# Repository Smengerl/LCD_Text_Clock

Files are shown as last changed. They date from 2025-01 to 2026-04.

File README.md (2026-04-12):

# LCD Text Clock





A text-based clock using an LCD display with I2C interface on an ESP microcontroller with automatic NTP time sync.

## Table of Contents
- [Mechanics](#mechanics)
- [Electronics](#electronics)
- [Software](#software)
- [Usage](#usage)
- [Customization Ideas](#customization-ideas)
- [Acknowledgements](#acknowledgements)
- [Development](#development)
- [License](#license)
- [Authors](#authors)

- Displays the current time and date as text like "five minutes to four"
- 16x2, 40*2 or 20x4 character LCD display support
- Customizable animations
- Supports buttons to flip between modes showing different informationwhich can be easily extended 
- Automatic backlight switching and dimming (optional feature) 
- Automatic time synchronization using NTP

The whole project rather serves as an example how text on a LCD display can be beautifully presented to users and can easily be extended/adapter to match your usecase.

| Without pushbuttons | With 4 pushbuttons |
| --- | ---|
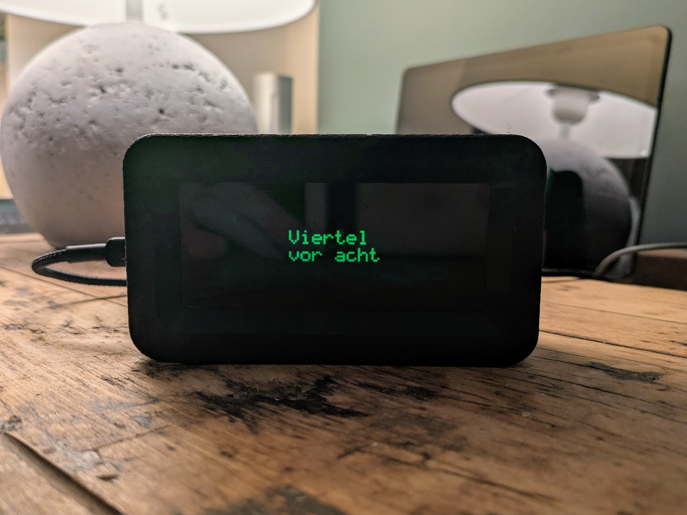
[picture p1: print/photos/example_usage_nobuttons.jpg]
example_usage_nobuttons
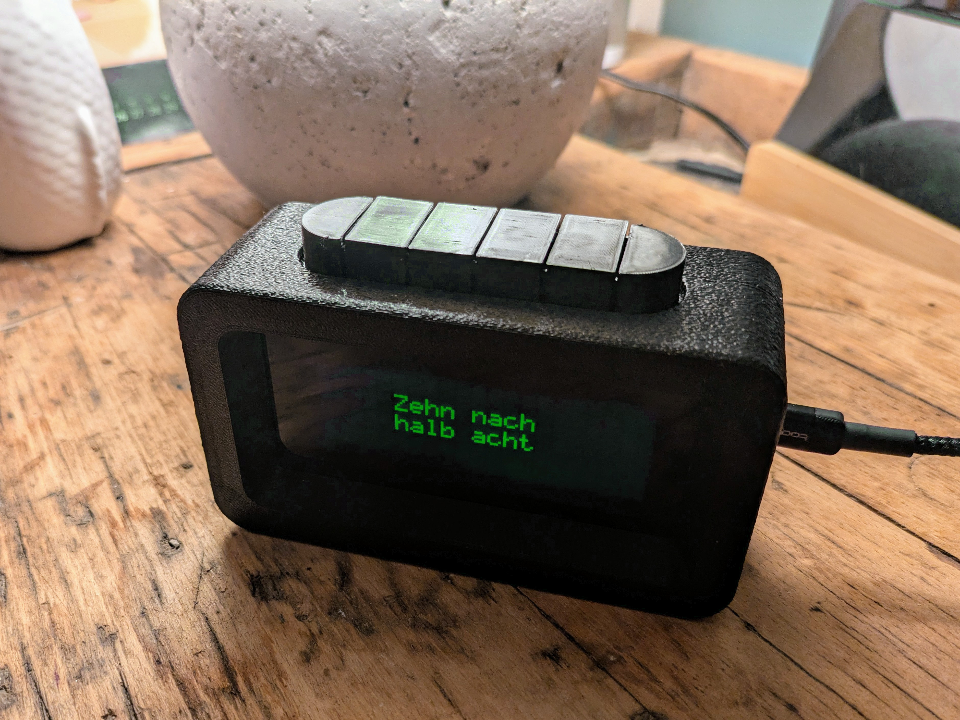
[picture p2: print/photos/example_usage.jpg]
example_usage
|   |  |

# Index
- [Mechanics](#Mechanics)
- [Electronics](#Electronics)
- [Software](#Software)
- [Usage](#Usage)
- [Customization ideas](#customization_ideas)
- [Acknowledgements](#Acknowledgements)

## Mechanics

Two different types of housings for 20*4 LCD displays are provided.
Using the acrylic plate on top of the LCD is optional but gives a cleaner look (not used in the example photos)

Very simple housing that consist of a front and a back piece (Shown is the version with the pushbuttons)

| Front | Back | Isometric |
| --- | --- | --- |
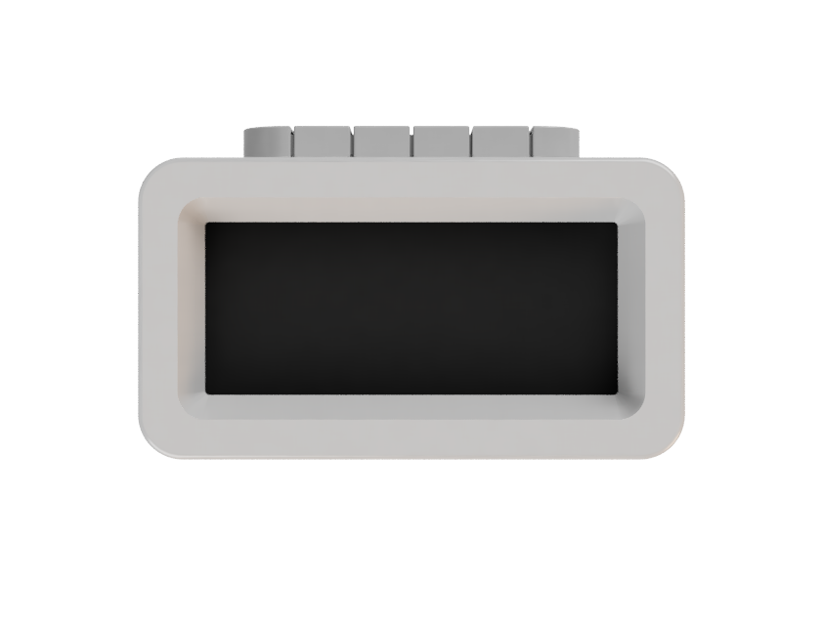
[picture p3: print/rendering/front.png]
front
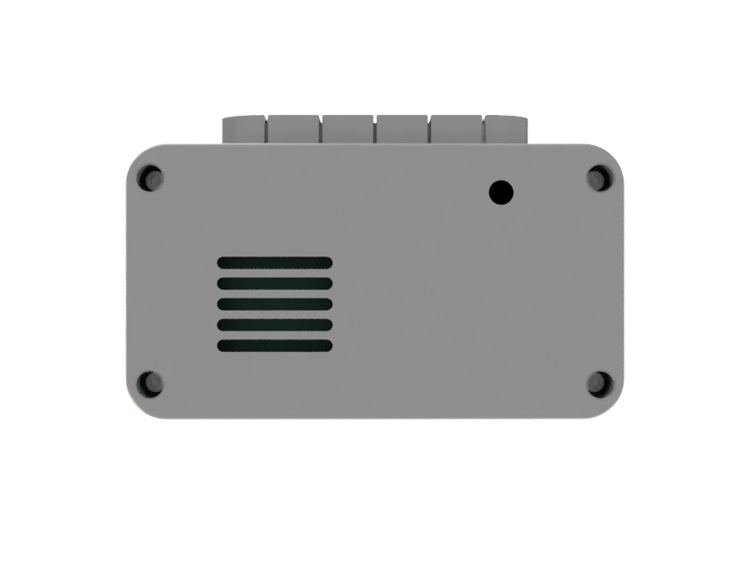
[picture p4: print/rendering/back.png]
back
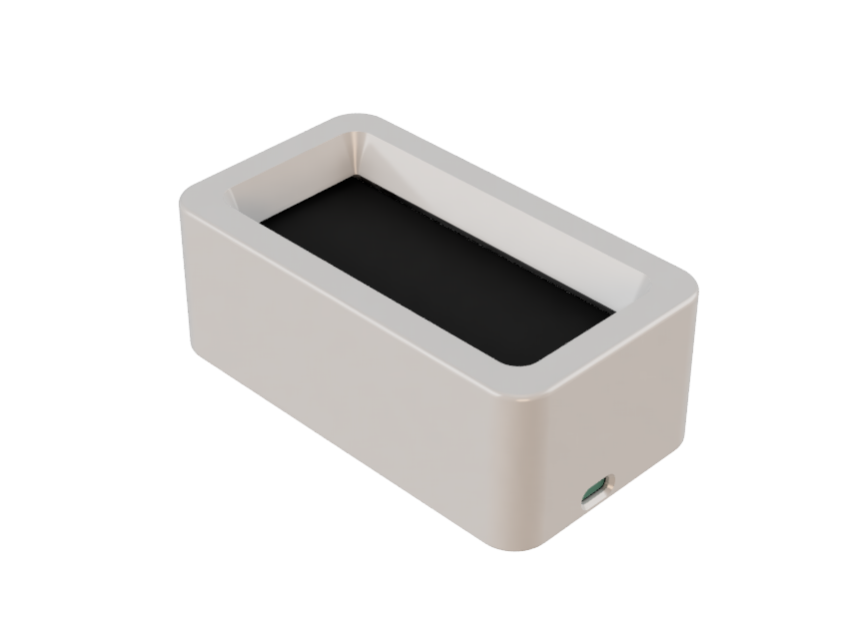
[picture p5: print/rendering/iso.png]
|  |  |  |
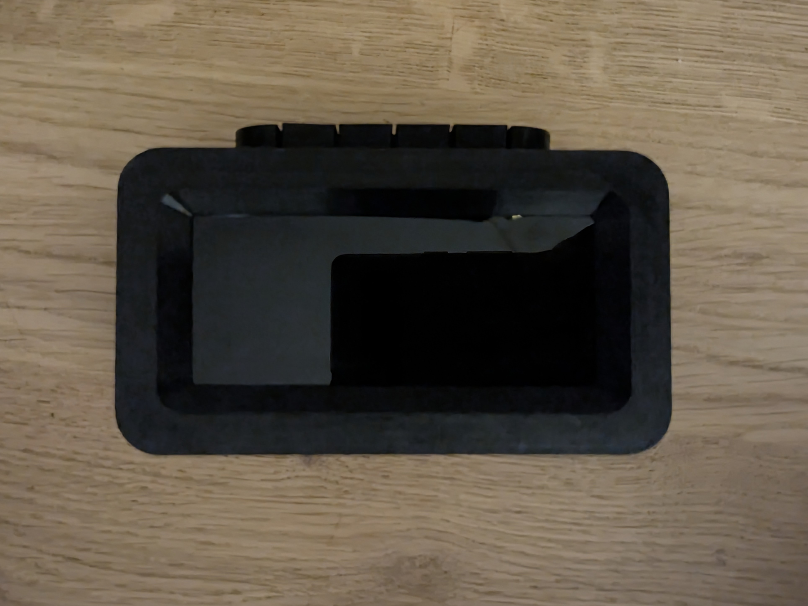
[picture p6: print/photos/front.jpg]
front
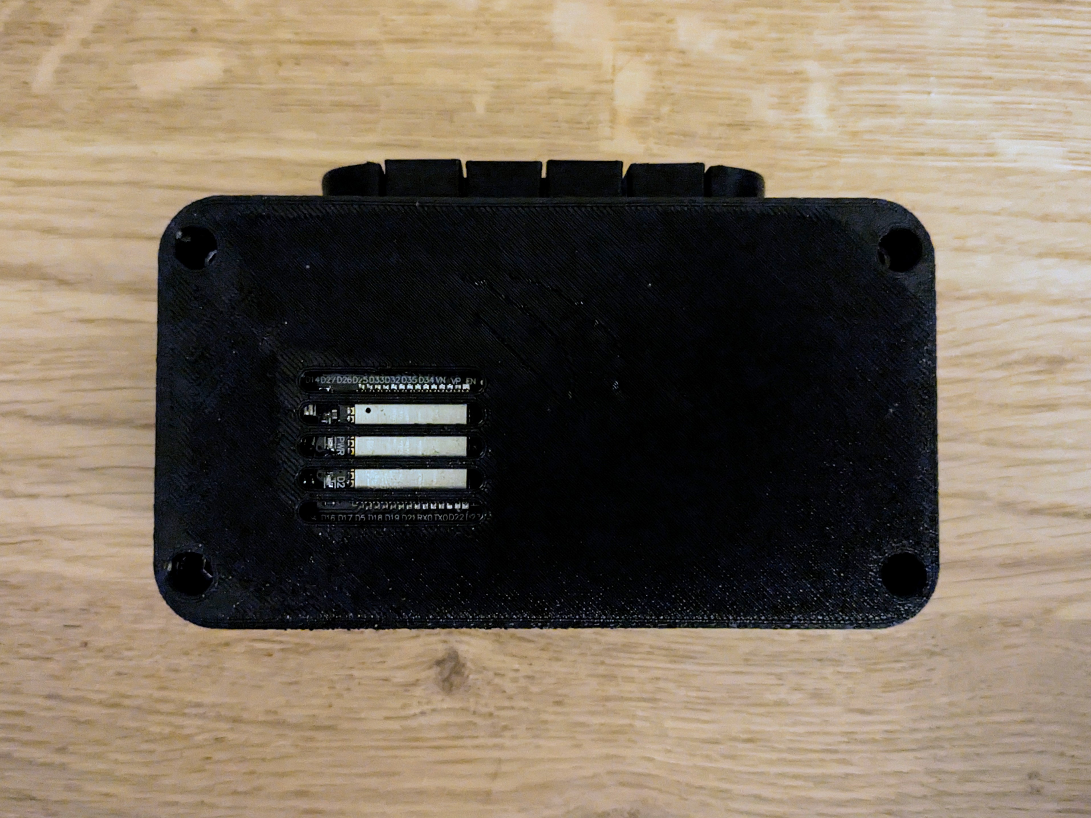
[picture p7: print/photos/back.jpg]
back
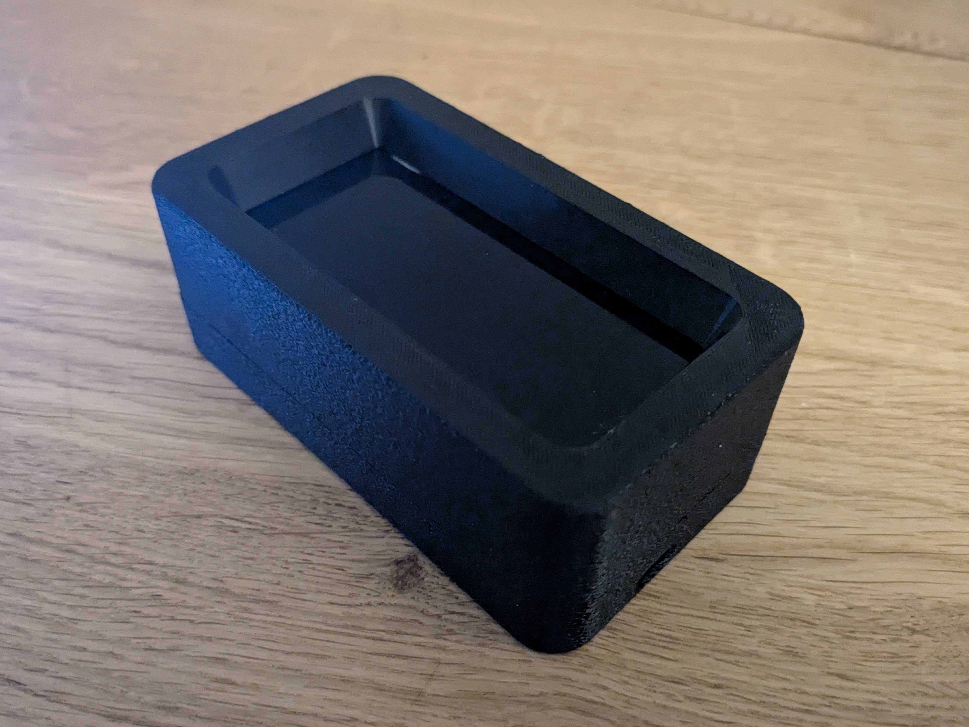
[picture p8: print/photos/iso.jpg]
|  |  |  |

### 3D-Printed Parts

1. Without pushbuttons:

| Filename | Thumbnail | Required | Notes |
| --- | ---| --- | ---|
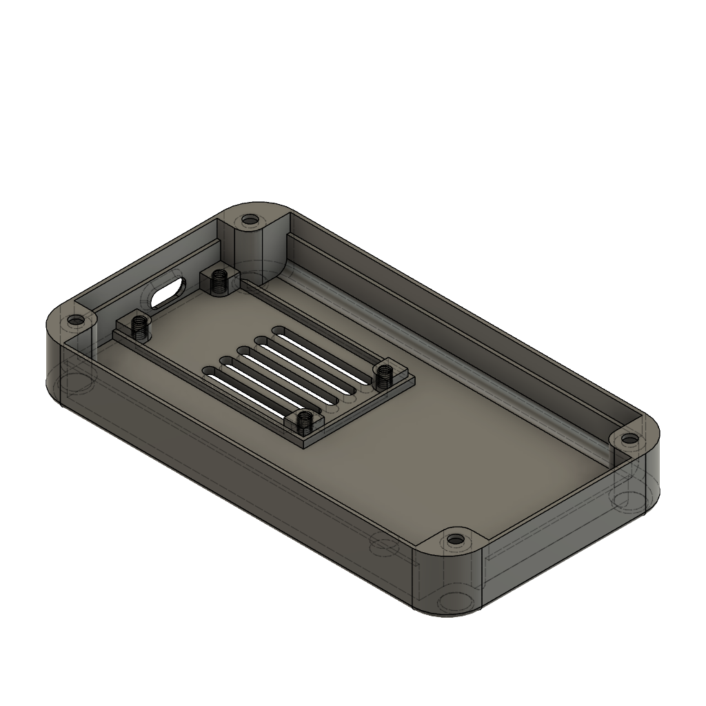
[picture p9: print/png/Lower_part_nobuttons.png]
Lower part
| `./print/stl/Lower_part_nobuttons.stl` |  | 1 | |
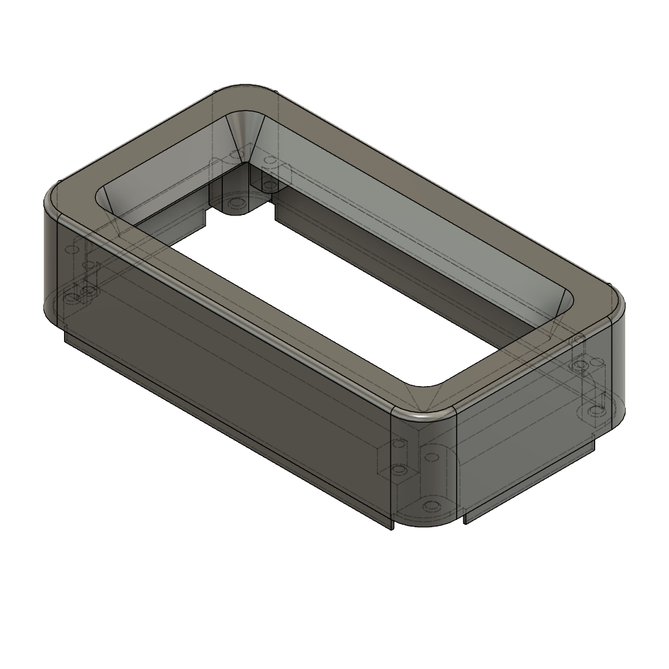
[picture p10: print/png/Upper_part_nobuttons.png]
Upper part
| `./print/stl/Upper_part_nobuttons.stl` |  | 1 | |

2. With 4 pushbuttons:

| Filename | Thumbnail | Required | Notes |
| --- | ---| --- | ---|
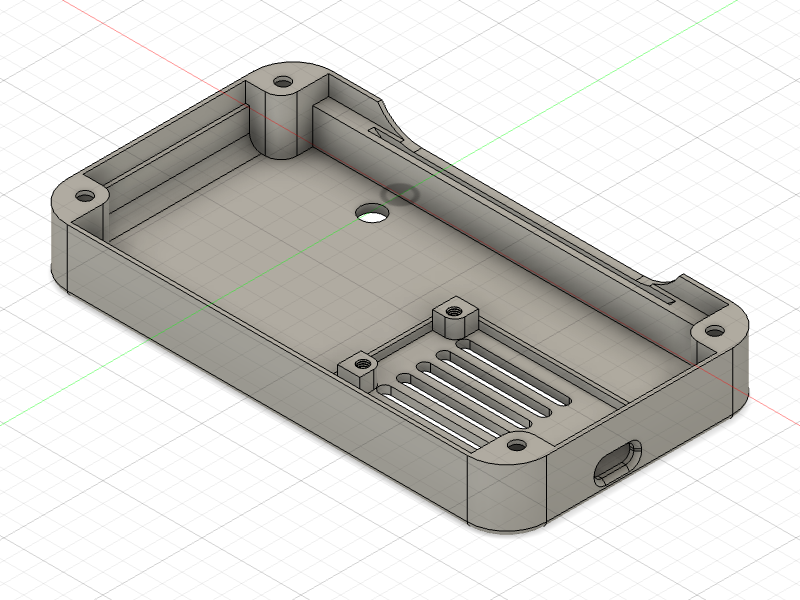
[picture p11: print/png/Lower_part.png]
Lower part
| `./print/stl/Lower_part.stl` |  | 1 | |
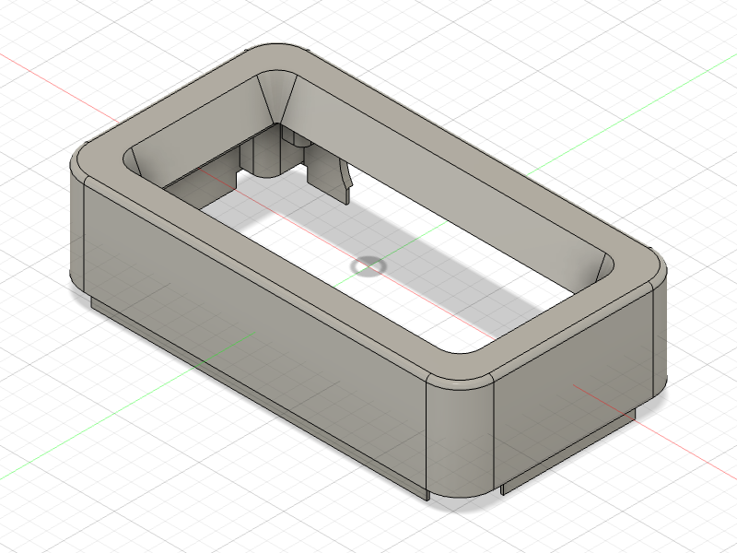
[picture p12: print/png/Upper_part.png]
Upper part
| `./print/stl/Upper_part.stl` |  | 1 | |
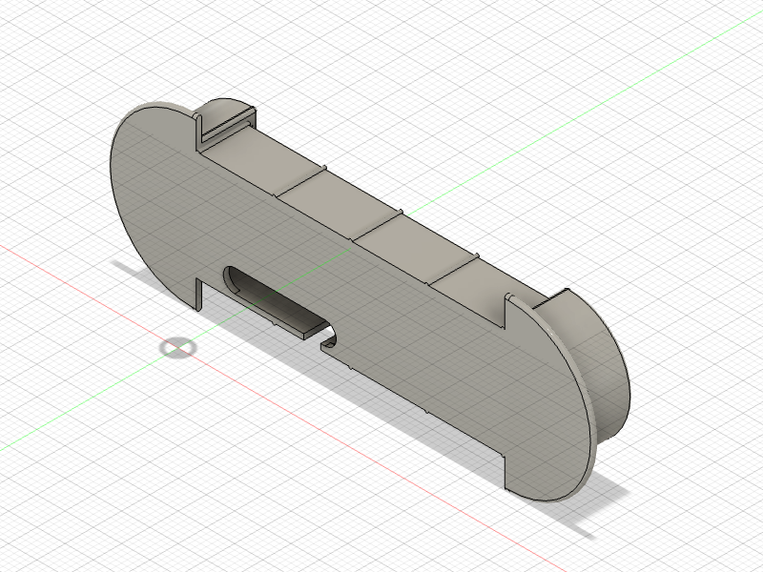
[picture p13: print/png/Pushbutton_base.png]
Pushbutton_base
| `./print/stl/Pushbutton_base.stl`  |  | 1 | |
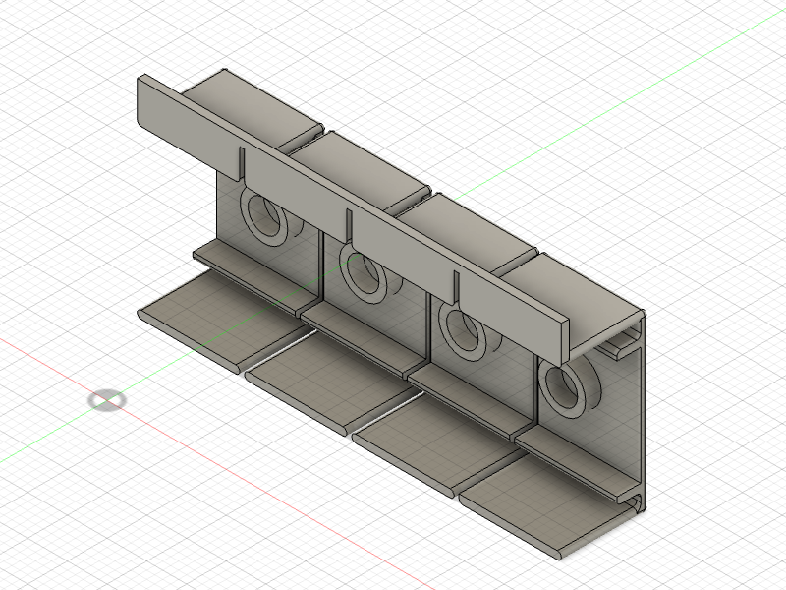
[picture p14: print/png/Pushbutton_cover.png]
Pushbutton_cover
| `./print/stl/Pushbutton_cover.stl` |  | 1 | |

Printer settings:
- All printed parts designed for PETG. 
- Best experience on my printer was to print the front upside down (the actual front of the case facing the print bed) as this does not require any supports. For a cleaner look you can consider to print it reversed with ironing enabled but note that this requires a lot of support material. 
- Using fuzzy skin for all outside walls creates a nice look
- Use ironing to get a nice clean look on top of the pushbutton baseplate and cover
- No rafts/brim etc. reguired for any model.

### Required parts

| Name | Spec | Required | Notes |
| --- | --- | --- | ---|
| countersunk screw | M3 5mm, e.g. DIN EN ISO 4762  | 4 | To attach ESP to back of housing |
| countersunk screw | M3 5mm, e.g. DIN EN ISO 4762  | 4 | To attach display to back of housing |
| cylinder head screw | M3 10mm | 4 | To fix back and front of housing |
| semi-transparent acrylic board | max 2mm, 95-100mm * 40-50mm | 1 | Optional, for cleaner look |

### Assembly

- The ESP is screwed to the back of the housing.
- The acrylic plate is glued to the front (optional)
- The LCD is then fixed via screws to the front
- When using the pushbuttons, click the pushbutton PCB into the baseplate and snap-in the pushbutton top cover. Then slide it into the lower part of the housing  
- Finally the lower and the upper part of the housing are assembled and tightened via the screws.
- Consider using some hot glue to make sure everything stays in place

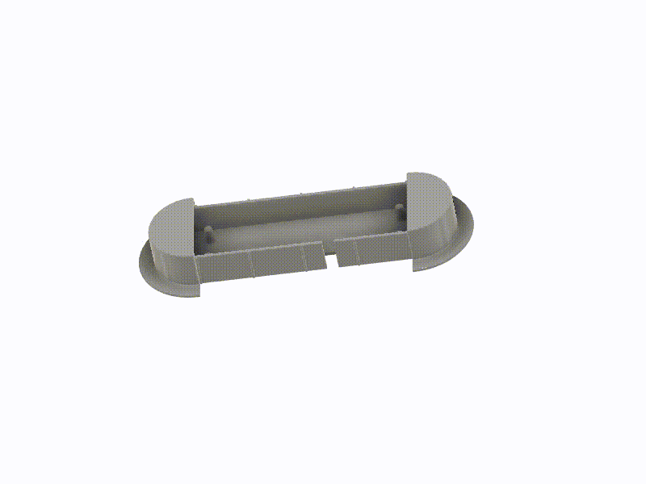
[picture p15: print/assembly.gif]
assembly


## Electronics

### Part list

| Unit price | Quantity | Partname | Example | Notes |
| --- | --- | --- | --- | ----- |
| 5 USD | 1 | ESP32 Dev module | <a href="https://de.aliexpress.com/item/1005006474308440.html">AliExpress</a> | USB-C Version |
| 5 USD | 1 | 2004 HD44780 character LCD module | <a href="https://de.aliexpress.com/item/1005006656450425.html">AliExpress</a> | Consider "negative" LCD (colored fonts on black background), as this gives a clean look, esp. when placing under an acrylic plate |
| 1-2 USD | 1 | PCF8574 I2C module for LCD | <a href="https://de.aliexpress.com/item/1005006686091415.html">AliExpress</a> | You might want to pick one that has a jumper to enable/disable backlight as we can "misuse" this to dim the backlight via GPIO |
| 1-2 USD | Optional | 4 button module | <a href="https://de.aliexpress.com/item/1005007272677522.html">AliExpress</a> | Optional | Unsolder SMD LED |

Total cost about 10-15 USD!

### Schematics

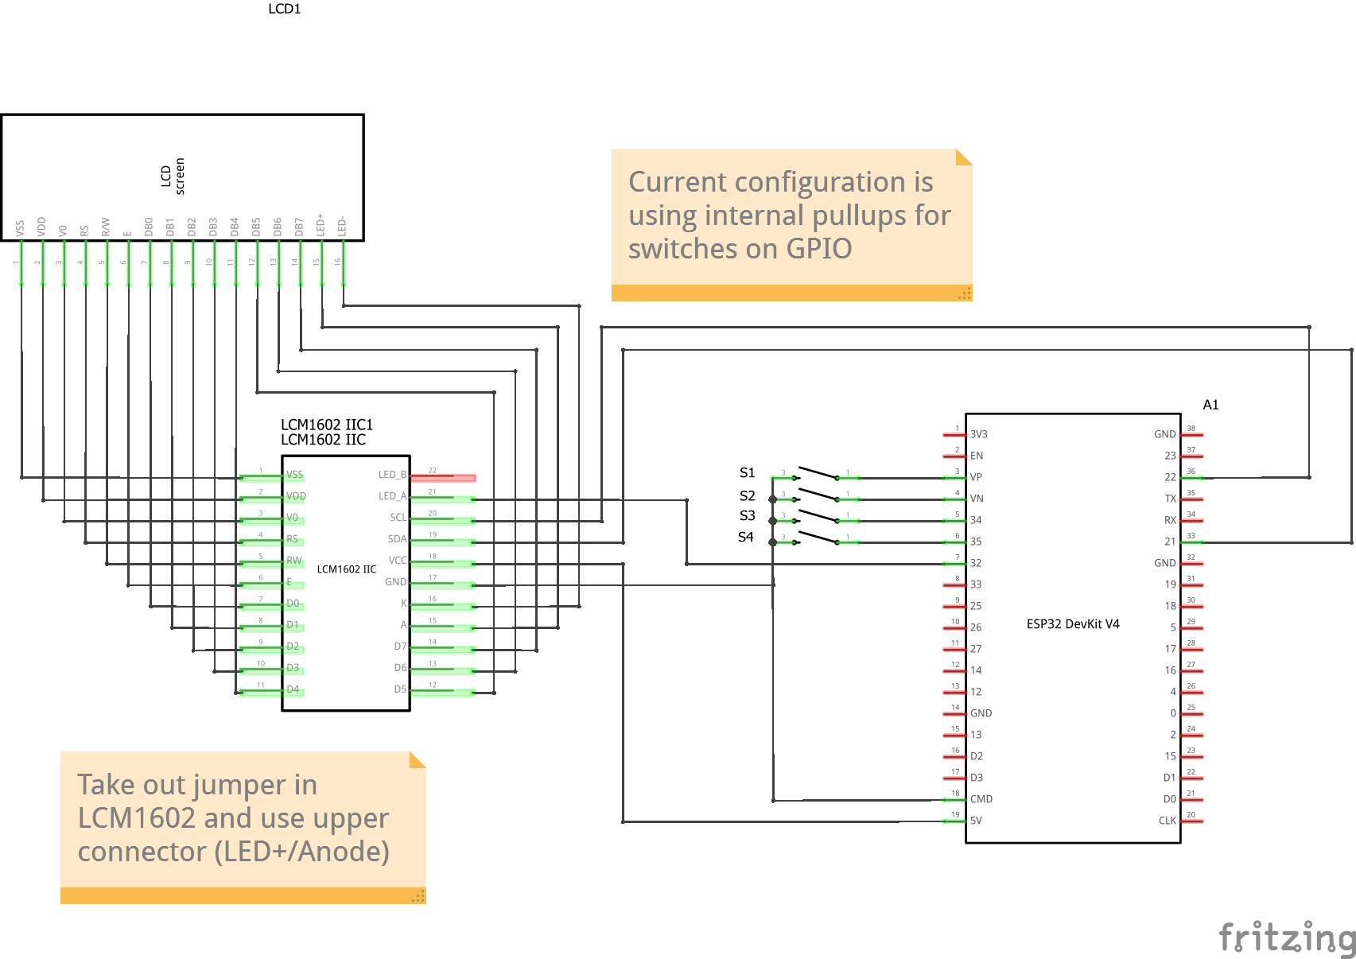
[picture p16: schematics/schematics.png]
schematics


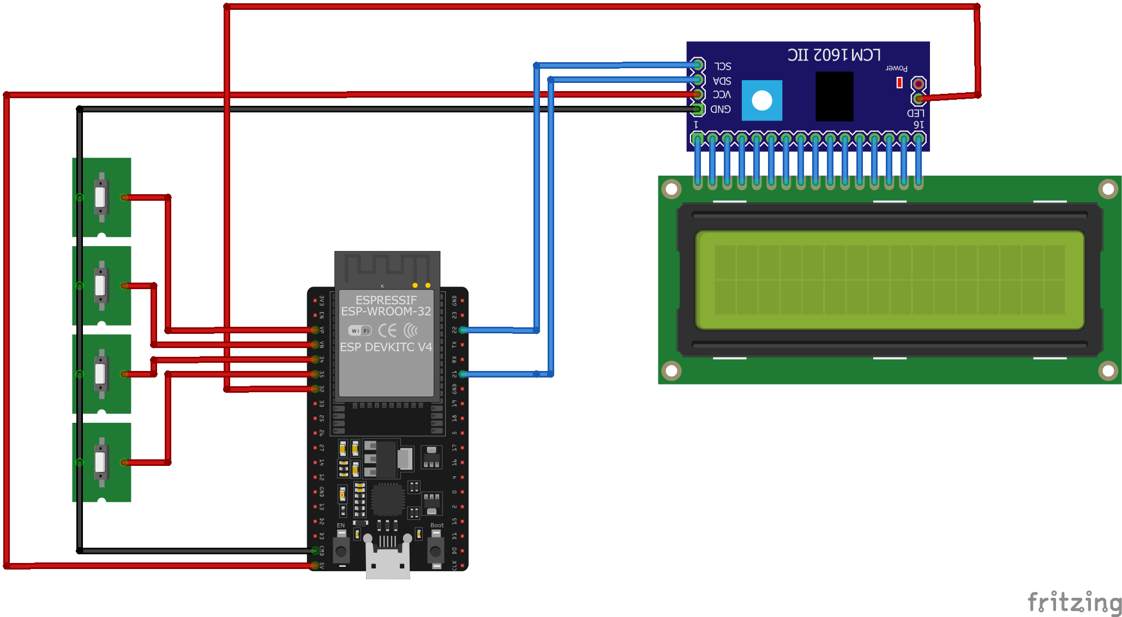
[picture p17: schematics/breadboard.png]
schematics


## Software

### Prerequisites

- PlatformIO
- LiquidCrystal_I2C (via PIO)
- ESPDateTime (via PIO)
- WiFiManager (via PIO)

### Installation

1. Clone the repository:
   ```sh
   git clone https://github.com/smengerl/LCD_Text_Clock.git
2. Open the project in PlatformIO.
3. Wait for PIO to configure and download the required libraries
4. Compile and upload the project to your ESP32 microcontroller.

## Usage
- Power on the ESP32.
- On first usage only: Configure the ESP to your local WiFi. For this, connect to the ESP's access point and use the default configuration page to enter your WLAN SSID and password 
- Wait for NTP sync
- The current time will be displayed on the LCD display.
- Use the (optional) buttons to flip through the pages and watch the animation

## Customization ideas

- Modify the text and backlight settings in the code to customize the display.
- Adjust the NTP server and time zone settings as needed.
- Add more pages, e.g. showing sensor data
- Get weather forecast via internet and display it on the screen with custom characters
- Write your own animations for text transitions

## Acknowledgements
- ESPDateTime library by mcxiaoke
- WiFiManager by wnatth3
- LiquidCrystal_I2C by marcoschwartz

## Development

Contributions are welcome.  
See `CONTRIBUTING.md` for details and follow the `CODE_OF_CONDUCT.md` when contributing.

All .stl, .png, and assembly pictures are automatically exported via my Fusion add-in, see [here](https://github.com/smengerl/fusion-exporter)

## License

This project is licensed under the Creative Commons Attribution-ShareAlike 4.0 International License (CC BY-SA 4.0) — see `LICENSE.txt` for details or visit http://creativecommons.org/licenses/by-sa/4.0/

## Authors

- Simon Gerlach <https://github.com/Smenger>

---

If something in this README is missing or unclear, please open an issue in the repository so the instructions can be improved.

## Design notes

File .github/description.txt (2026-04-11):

Multi purpose textual clock with LCD (HDD44780) based on ESP32

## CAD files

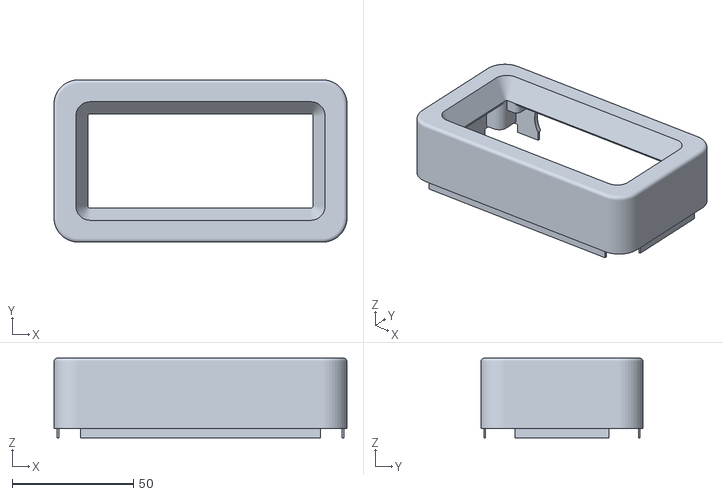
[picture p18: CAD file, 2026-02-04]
print/stl/Upper_part.stl
121.0 x 67.0 x 33.0

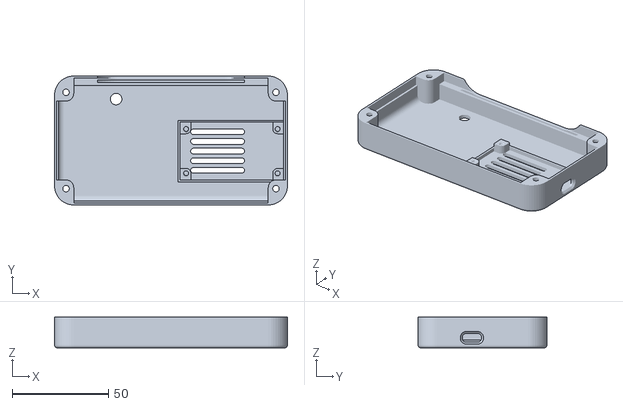
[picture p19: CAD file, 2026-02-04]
print/stl/Lower_part.stl
121.0 x 67.0 x 16.0

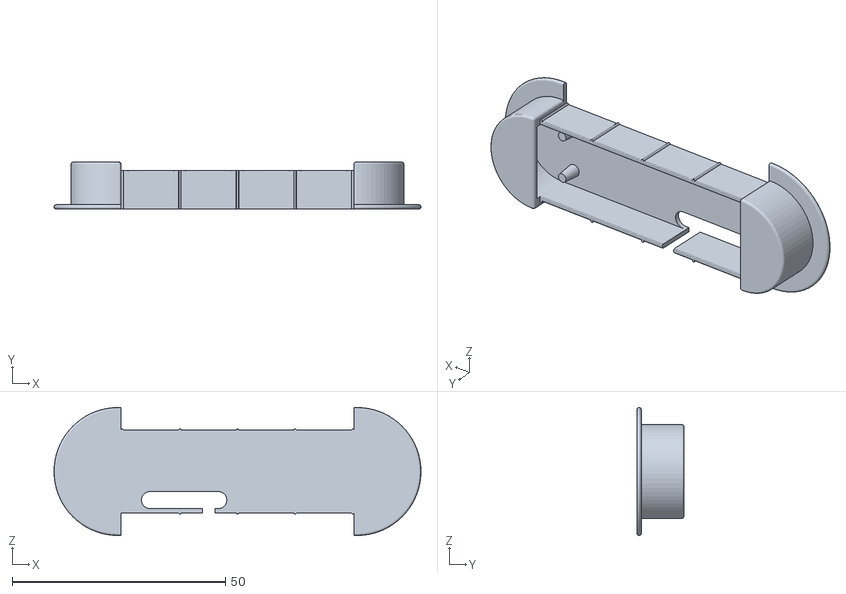
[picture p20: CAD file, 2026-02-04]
print/stl/Pushbutton_base.stl
86.0 x 11.0 x 30.0

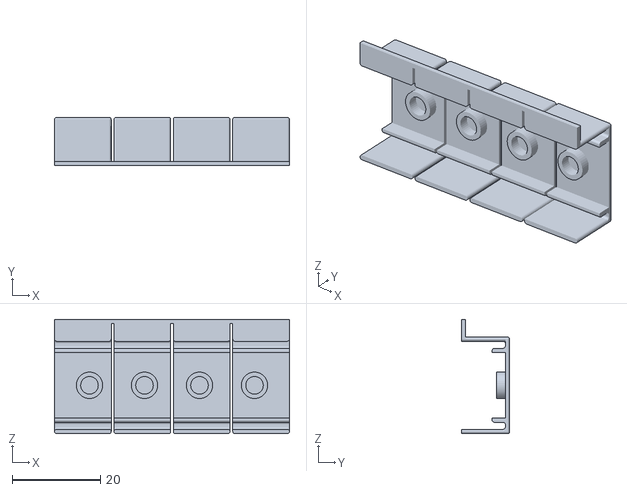
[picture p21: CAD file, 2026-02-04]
print/stl/Pushbutton_cover.stl
53.4 x 11.0 x 26.0

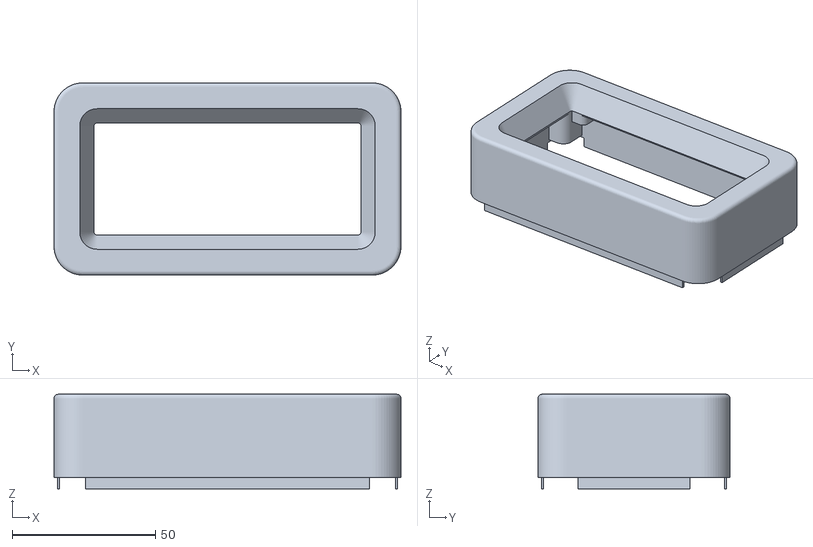
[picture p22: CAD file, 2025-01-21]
print/stl/Upper_part_nobuttons.stl
121.0 x 67.0 x 33.0

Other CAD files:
print/stl/Lower_part_nobuttons.stl
print/fusion_export.f3z

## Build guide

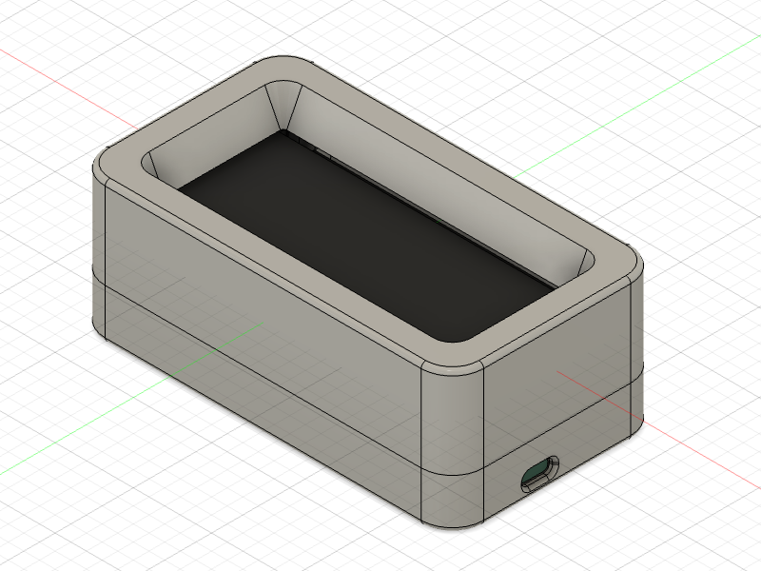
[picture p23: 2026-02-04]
print/zsb/full.png

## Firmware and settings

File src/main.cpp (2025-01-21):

#include <Arduino.h>

#include <cstring>

#include "TextHelper.hpp"
#include "TextAnimation.hpp"
#include "TextAlignments.hpp"

#include <LiquidCrystal_I2C.h>
#include <WiFiManager.h>
#include <WiFi.h>
#include "ESPDateTime.h"
#include "config.h"
#include "esp_bt.h"

#include <freertos/FreeRTOS.h>
#include <freertos/task.h>
#include <freertos/semphr.h>

#include "lcd_text_clock_config.hpp"



// PAGES ****************************************************

enum t_page {
#ifdef HAS_PAGE_TIME
  PAGE_TIME,
#endif
#ifdef HAS_PAGE_DATE
  PAGE_DATE,
#endif
  MAX_VALUE
};

#if !defined(HAS_PAGE_TIME)
#if !defined(HAS_PAGE_DATE)
  #error No page defined!
#endif
#endif


#if (LCD_LINES != 4 && LCD_LINES != 2)
#error "LCD_LINES must be 1, 2 or 4"
#endif
#if (LCD_LINES == 4 && LCD_CHAR_PER_LINE != 20)
#error "Unsupported display type: 4 line display must have 20 character"
#endif
#if (LCD_LINES == 2 && LCD_CHAR_PER_LINE != 16)
#error "Unsupported display type: 2 line display must have 16 character"
#endif



t_page page(START_PAGE);




// VARS ****************************************************

// LCD
LiquidCrystal_I2C lcd(I2C_ADDRESS_LCD, LCD_CHAR_PER_LINE, LCD_LINES);

// Cached weight table for faster text layouting
uint8_t* weights = createWeightTable(LCD_CHAR_PER_LINE, LCD_LINES, H_TEXT_ALIGNMENT, V_TEXT_ALIGNMENT);

// Animation helper object
TextAnimation animation(LCD_CHAR_PER_LINE, LCD_LINES);






#define STRING_BUFFER_SIZE LCD_CHAR_PER_LINE * LCD_LINES + 20
char last_stable_text[STRING_BUFFER_SIZE] = "";



uint32_t displayOnUntil = 0;      













void printToLcd(char *s) {
  char buf[STRING_BUFFER_SIZE];
  formatString(buf, s, LCD_CHAR_PER_LINE, LCD_LINES, weights);
  lcd.setCursor(0, 0);
  lcd.printstr(buf);
}



// BACKLIGHT HANDLING *****************************************


#ifdef HAS_BACKLIGHT

  bool backlightEnabled;

  bool isBacklightEnabled() {
    return backlightEnabled;
  }

  void setBacklightEnabled(bool value) {
    if (value) {
      log_d("Backlight enabled");
    } else {
      log_d("Backlight disabled");
    }
    digitalWrite(PIN_LCD_BACKLIGHT, value);
    backlightEnabled = value;
  }

  void setBacklightEnabled(bool value, uint16_t duration) {
    if (backlightEnabled == value) return;

    // "Forecast" final value
    backlightEnabled = value;

    if (duration > 0) {
      if (value) {
        // Dimmen zum Einschalten
        log_d("Dim backlight from off to on in %d ms", duration);
        for (int i = 0; i < duration; i = i + DIMMING_BACKLIGHT_STEPSIZE) {
          float t = ((float)255 * i) / duration;
          analogWrite(PIN_LCD_BACKLIGHT, (int)t);
          vTaskDelay(pdMS_TO_TICKS(DIMMING_BACKLIGHT_STEPSIZE));
        }
      } else {
        // Dimmen zum Ausschalten
        log_d("Dim backlight from on to off in %d ms", duration);
        for (int i = 0; i < duration; i = i + DIMMING_BACKLIGHT_STEPSIZE) {
          float t = 255 - ((float)255 * i) / duration;
          analogWrite(PIN_LCD_BACKLIGHT, (int)t);
          vTaskDelay(pdMS_TO_TICKS(DIMMING_BACKLIGHT_STEPSIZE));
        }
      }
    }
    // Finally use regular "digital" write to ensure the backlight is fully on/off
    setBacklightEnabled(value);
  }



  SemaphoreHandle_t backlightSemaphore = NULL;

  /**
   * Helper function to be used in separate task to run asynchronously
   */
  void fadeBacklightTask(void *pvParameters) {
    if (backlightSemaphore == NULL) {
      backlightSemaphore = xSemaphoreCreateBinary();
    } else {
      if (!xSemaphoreTake(backlightSemaphore, pdMS_TO_TICKS(
        _max(BACKLIGHT_DIMMING_DURATION_ON, BACKLIGHT_DIMMING_DURATION_OFF)))) {

        log_e("Timeout taking semaphore for backlight fading!");
        vTaskDelete(NULL); 
      }
    }

    // The parameter provided when the task was created determines if this is to fade the backlight in or out
    if ((bool) pvParameters ) {
      setBacklightEnabled(true, BACKLIGHT_DIMMING_DURATION_ON);
    } else {
      setBacklightEnabled(false, BACKLIGHT_DIMMING_DURATION_OFF);
    }
    
    xSemaphoreGive(backlightSemaphore);
    vTaskDelete(NULL); // Delete this task when done
  }


#endif










// NTP *****************************************

SemaphoreHandle_t ntpSyncSemaphore = NULL;

void DateTimeTask(void *pvParameters) {
  
  log_i("NTP synching, please wait... ");

  DateTime.setServer(NTP_SERVER);
  DateTime.setTimeZone(TIMEZONE);

  while (!DateTime.begin(NTP_SYNC_TIMEOUT)) {
    log_i("Timeout, retrying\n");
  }
  log_i("Sync NTP done");

  log_d("Date Now is %s\n", DateTime.toISOString().c_str());
  log_d("Timestamp is %ld\n", DateTime.now());

  xSemaphoreGive(ntpSyncSemaphore); // Give the semaphore to signal task completion
  vTaskDelete(NULL); // Delete this task when done
}

void setupDateTime() {
  printToLcd("NTP Sync");

  ntpSyncSemaphore = xSemaphoreCreateBinary(); // Create the semaphore
  xTaskCreate(
    DateTimeTask, // Task function
    "NTPSync",    // Name of the task
    4096,         // Stack size (in words)
    NULL,         // Task input parameter
    1,            // Priority of the task
    NULL          // Task handle
  );

  while (!xSemaphoreTake(ntpSyncSemaphore, pdMS_TO_TICKS(500))) { 
    Serial.print(".");
  }
  vSemaphoreDelete(ntpSyncSemaphore); // Delete the semaphore
}







// HARDWARE INITALIZATION *****************************************

void setupWiFi() {
  //WiFiManager, Local variable sufficient as once its business is done, there is no need to keep it any longer
  WiFiManager wm;

  log_i("WiFi connecting... ");

  char buf[100];
  snprintf(buf, sizeof(buf), "To setup Wifi connect to: %s", wm.getDefaultAPName().c_str());
  printToLcd(buf);

  // reset settings - wipe stored credentials for testing
  // these are stored by the esp library
  // wm.resetSettings();

  wm.setConfigPortalBlocking(false); // asynchroneous mode in order to display the message on the LED matrix
  if (!wm.autoConnect()) { // Try to reconnect to last WiFi or open non password protected AP with default name
    while (!wm.process()) {
      Serial.print(".");
    }
    log_i("WiFi successfully connected (using manual config in AP portal)");
  } else {
    log_i("WiFi successfully connected (using saved credentials)");
  }
}

void disableWiFi() {
  WiFi.disconnect(true);
  WiFi.mode(WIFI_OFF);
  log_i("WiFi disabled");
}

// Function to disable Bluetooth
void disableBluetooth() {
  if (esp_bt_controller_get_status() == ESP_BT_CONTROLLER_STATUS_ENABLED) {
      esp_err_t ret = esp_bt_controller_disable();
      if (ret != ESP_OK) {
          log_e("Bluetooth disable failed: %s\n", esp_err_to_name(ret));
          return;
      }
  }

  if (esp_bt_controller_get_status() == ESP_BT_CONTROLLER_STATUS_INITED) {
      esp_err_t ret = esp_bt_controller_deinit();
      if (ret != ESP_OK) {
          log_e("Bluetooth deinit failed: %s\n", esp_err_to_name(ret));
          return;
      }
  }

  log_i("Bluetooth disabled");
}


void setupLCD() {
    // enable LCD backlight
  pinMode(PIN_LCD_BACKLIGHT, OUTPUT);
  #ifdef HAS_BACKLIGHT
    setBacklightEnabled(true);
  #endif

  lcd.init(); 
  lcd.clear();
  lcd.noCursor();
  lcd.noBlink();
  lcd.display();
  lcd.backlight();
}


#ifdef HAS_BUTTONS
  void setupButtons() {
    pinMode(PIN_BUTTON_1, INPUT_PULLDOWN);
    pinMode(PIN_BUTTON_2, INPUT_PULLDOWN);
    pinMode(PIN_BUTTON_3, INPUT_PULLDOWN);
    pinMode(PIN_BUTTON_4, INPUT_PULLDOWN);
  }
#endif

void setup() {
  Serial.begin(115200);

  setupLCD();

  disableBluetooth();

  // Sync with NTP only on initial startup. After that, power off Wifi to save energy
  setupWiFi();
  setupDateTime();
  disableWiFi();

  #ifdef HAS_BUTTONS
    setupButtons();
  #endif

  // pinMode(PIN_ENCODER_SW, INPUT_PULLUP);

  // Attach rotary encoder press to interrupt callback on any change
  //  attachInterrupt(digitalPinToInterrupt(ENCODER_SW), Interrupt, CHANGE);
  // Enable Interrupt handling just in case
  //  interrupts();

  last_stable_text[0] = 0;
}




#ifdef HAS_PAGE_TIME
  /// @brief Generates the text to display for the page "time"
  /// @param s Pointer to the string buffer to write the time to
  /// @param now The date and time to display
  void pageTime(char *s, tm now) {
    switch (now.tm_min) {
      case 0:
      case 1:
      case 2:
        snprintf(s, STRING_BUFFER_SIZE, "%s", getHourOfTheDayLong(now.tm_hour));
        break;

      case 3:
      case 4:
      case 5:
      case 6:
      case 7:
        snprintf(s, STRING_BUFFER_SIZE, "Fünf nach %s", getHourOfTheDay(now.tm_hour));
        break;

      case 8:
      case 9:
      case 10:
      case 11:
      case 12:
        snprintf(s, STRING_BUFFER_SIZE, "Zehn nach %s", getHourOfTheDay(now.tm_hour));
        break;

      case 13:
      case 14:
      case 15:
      case 16:
      case 17:
        snprintf(s, STRING_BUFFER_SIZE, "Viertel nach %s", getHourOfTheDay(now.tm_hour));
        break;

      case 18:
      case 19:
      case 20:
      case 21:
      case 22:
        snprintf(s, STRING_BUFFER_SIZE, "Zehn vor halb %s", getHourOfTheDay((now.tm_hour + 1) % 24));
        break;

      case 23:
      case 24:
      case 25:
      case 26:
      case 27:
        snprintf(s, STRING_BUFFER_SIZE, "Fünf vor halb %s", getHourOfTheDay((now.tm_hour + 1) % 24));
        break;

      case 28:
      case 29:
      case 30:
      case 31:
      case 32:
        snprintf(s, STRING_BUFFER_SIZE, "Halb %s", getHourOfTheDay((now.tm_hour + 1) % 24));
        break;

      case 33:
      case 34:
      case 35:
      case 36:
      case 37:
        snprintf(s, STRING_BUFFER_SIZE, "Fünf nach halb %s", getHourOfTheDay((now.tm_hour + 1) % 24));
        break;

      case 38:
      case 39:
      case 40:
      case 41:
      case 42:
        snprintf(s, STRING_BUFFER_SIZE, "Zehn nach halb %s", getHourOfTheDay((now.tm_hour + 1) % 24));
        break;

      case 43:
      case 44:
      case 45:
      case 46:
      case 47:
        snprintf(s, STRING_BUFFER_SIZE, "Viertel vor %s", getHourOfTheDay((now.tm_hour + 1) % 24));
        break;

      case 48:
      case 49:
      case 50:
      case 51:
      case 52:
        snprintf(s, STRING_BUFFER_SIZE, "Zehn vor %s", getHourOfTheDay((now.tm_hour + 1) % 24));
        break;

      case 53:
      case 54:
      case 55:
      case 56:
      case 57:
        snprintf(s, STRING_BUFFER_SIZE, "Fünf vor %s", getHourOfTheDay((now.tm_hour + 1) % 24));
        break;

      case 58:
      case 59:
        snprintf(s, STRING_BUFFER_SIZE, "%s", getHourOfTheDayLong((now.tm_hour + 1) % 24));
        break;

      default:
        log_e("Inplausible time!");
        snprintf(s, STRING_BUFFER_SIZE, "FEHLER! Unplausible Uhrzeit");
    }
  }
#endif


#ifdef HAS_PAGE_DATE
  /// @brief Generates the text to display for the page "date"
  /// @param s Pointer to the string buffer to write the date to
  /// @param now The date and time to display
  void pageDate(char *s, tm now) {
    const char* month = getMonthOfTheYear(now.tm_mon);
    const char* dayOfTheWeek = getDayOfTheWeek(now.tm_wday);
    snprintf(s, STRING_BUFFER_SIZE, "%s der %d. %s", dayOfTheWeek, now.tm_mday, month);
  }
#endif



#ifdef HAS_BUTTONS
  // Last state of buttons
  bool t1, t2, t3, t4;
#endif

/// @brief Core loop executed repeatedly after initialization
void loop() {
  unsigned long t0 = micros();

  time_t now = DateTime.now();
  struct tm *tm = localtime(&now);

  // Adjust for daylight saving time if necessary
  if (tm->tm_isdst > 0) {
    tm->tm_hour += 1;
    mktime(tm); // Normalize the time structure
  }


  #ifdef HAS_BUTTONS
    bool t1_pos = false;
    if (!digitalRead(PIN_BUTTON_1)) {
      // Button pressed
      if (!t1) {
        t1 = true;
        t1_pos = true;
      }
    } else {
      t1 = false;
    }

    bool t2_pos = false;
    if (!digitalRead(PIN_BUTTON_2)) {
      // Button pressed
      if (!t2) {
        t2 = true;
        t2_pos = true;
      }
    } else {
      t2 = false;
    }

    bool t3_pos = false;
    if (!digitalRead(PIN_BUTTON_3)) {
      // Button pressed
      if (!t3) {
        t3 = true;
        t3_pos = true;
      }
    } else {
      t3 = false;
    }

    bool t4_pos = false;
    if (!digitalRead(PIN_BUTTON_4)) {
      // Button pressed
      if (!t4) {
        t4 = true;
        t4_pos = true;
      }
    } else {
      t4 = false;
    }

    #ifdef HAS_BACKLIGHT
      // Activate backlight for predefined time after button was pressed or turned
      #ifdef BACKLIGHT_ON_TIME
        if (
          t1 || t2 || t3 || t4 // Any key pressed?
          || displayOnUntil == 0  // ... on startup
        ) {
          // Turn on display
          log_i("Trigger display backlight");

          displayOnUntil = now + BACKLIGHT_ON_TIME;
        }

        if (now < displayOnUntil) {
          if (!isBacklightEnabled()) {
            log_i("Turning Backlight on...");
            #ifdef BACKLIGHT_DIMMING_DURATION_ON
              xTaskCreate(
                fadeBacklightTask, // Task function
                "fadeInBacklight", // Name of the task
                4096,              // Stack size (in words)
                (void*)true,       // Task input parameter
                1,                 // Priority of the task
                NULL               // Task handle
              );
            #else
              setBacklightEnabled(true);
            #endif
            log_i("Backlight turned on");
          }
        } else {
          if (isBacklightEnabled()) {
            log_i("Turning Backlight off...");
            #ifdef BACKLIGHT_DIMMING_DURATION_OFF
              xTaskCreate(
                fadeBacklightTask,  // Task function
                "fadeOutBacklight", // Name of the task
                4096,               // Stack size (in words)
                (void*)false,       // Task input parameter
                1,                  // Priority of the task
                NULL                // Task handle
              );
            #else
              setBacklightEnabled(false);
            #endif
            log_i("Backlight turned off");
          }
        }
      #endif
    #endif
    
    if (t1_pos) {
      page = static_cast<t_page>(page + 1);
      if (page == t_page::MAX_VALUE) {
        page = static_cast<t_page>(0);
      }
      animation.start(ANIMATION_NEXT_PAGE_FRAMES, ANIMATION_NEXT_PAGE_TYPE);
      log_i("Next page: %d", page);
    }
    if (t4_pos) {
      page = (page) ? static_cast<t_page>(page - 1) : static_cast<t_page>(t_page::MAX_VALUE - 1);
      animation.start(ANIMATION_PREVIOUS_PAGE_FRAMES, ANIMATION_PREVIOUS_PAGE_TYPE);
      log_i("Previous page: %d", page);
    }
  #endif



  char s1[STRING_BUFFER_SIZE] = "";
  char s2[STRING_BUFFER_SIZE] = "";

  switch (page) {
#ifdef HAS_PAGE_TIME
    case t_page::PAGE_TIME:
      pageTime(s1, *tm);
      break;
#endif
#ifdef HAS_PAGE_DATE
    case t_page::PAGE_DATE:
      pageDate(s1, *tm);
      break;
#endif
#ifdef HAS_PAGE_TEMP
    case t_page::PAGE_TEMP:
      pageTemp(s1);
      break;
#endif
    default:
      log_e("Unknown page");
  }
  formatString(s2, s1, LCD_CHAR_PER_LINE, LCD_LINES, weights);

  // If a change in the text was detected and there is currently no running animation, then start an animation
  if (animation.isEnded() && strcmp(s2, last_stable_text) != 0) {
    animation.start(ANIMATION_TEXT_CHANGE_FRAMES, ANIMATION_TEXT_CHANGE_TYPE);
    log_i("Text change animation started");
  }

  // Render animation frame if still running
  if (!animation.isEnded()) {
    animation.tick();
    animation.apply(s1, last_stable_text, s2);

    lcd.setCursor(0, 0);
    lcd.printstr(s1);

    // if this was last frame and animation has now ended, then store the final state
    if (animation.isEnded()) {
      log_i("Animation endet");
      strcpy(last_stable_text, s1);
//      printStringToLCD(s2);
    } 
  } 


  unsigned long render_duration = (micros()-t0) / 1000;
  log_d("Rendering cycle took %dms (%d FPS)", render_duration, 1000/render_duration);

  // If animation not yet ended, then wait for remaining time of frame duration, else just go on as fast as possible
  if (!animation.isEnded()) {
    if (render_duration > ANIMATION_FRAME_DURATION) {
      log_w("Render cycle to slow, exceeded time");
    } else {
      vTaskDelay(pdMS_TO_TICKS(ANIMATION_FRAME_DURATION - render_duration));
    }

  } else {
    // Save some energy by limiting speed of idle loop
    if (render_duration < IDLE_CYCLE) {
      vTaskDelay(pdMS_TO_TICKS(IDLE_CYCLE - render_duration));
    }    
  }
}

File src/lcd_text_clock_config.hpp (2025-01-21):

#include "TextAnimation.hpp"



// ***********************************************************
// FEATURES
// ***********************************************************

// Pushbuttons supported
#define HAS_BUTTONS

// Smart background light
#define HAS_BACKLIGHT

// Pages
#define HAS_PAGE_TIME
#define HAS_PAGE_DATE

// Page to start with
#define START_PAGE PAGE_TIME


// ***********************************************************
// NTP SETTINGS
// ***********************************************************

/** Servername of NTP server to use to get the time from */
#define NTP_SERVER "pool.ntp.org" 

/** Which timezone we are in */
#define TIMEZONE "CET-1CEST,M3.5.0,M10.5.0/3" 

/** Max roundtrip time for NTP sync in ms */
#define NTP_SYNC_TIMEOUT 15000




// ***********************************************************
// HARDWARE
// ***********************************************************

// Minimum wait time between two loop cycles
#define IDLE_CYCLE 50

#ifdef HAS_BUTTONS
  // GPIO 36 --> T1
  // GPIO 39 --> T2
  // GPIO 34 --> T3
  // GPIO 35 --> T4
  #define PIN_BUTTON_1 36
  #define PIN_BUTTON_2 39
  #define PIN_BUTTON_3 34
  #define PIN_BUTTON_4 35
#endif

/** Make sure to use a analog output pin to be able to use PWM (3, 5, 6, 9, 10 and 11 on Uno) */
// GPIO 32 --> LCD Backlight
#define PIN_LCD_BACKLIGHT 32

// GPIO 22 --> LCD I2C SCL
// GPIO 21 --> LCD I2C SDA
#define I2C_ADDRESS_LCD 0x27




// ***********************************************************
// LCD
// ***********************************************************

// 20*4 character I2C display 
#define LCD_CHAR_PER_LINE 20
#define LCD_LINES 4


// ***********************************************************
// BACKLIGHT
// ***********************************************************

#ifdef HAS_BACKLIGHT
  /** 
   * Time in s to keep the display backlight on after user input 
   * Do not define if no dynamic backlight control is needed
   */
  #define BACKLIGHT_ON_TIME 10

  /** 
   * Time in ms to dim the backlight to full brightness. 
   * Do not define or set to 0 if no dimming shall happen
   */
  #define BACKLIGHT_DIMMING_DURATION_ON 500

  /** 
   * Time in ms to dim the backlight to off. 
   * Do not define or set to 0 if no dimming shall happen
   */
  #define BACKLIGHT_DIMMING_DURATION_OFF 2000

  /**
   * Steps in ms to fade in/out of backlight
   */
  #define DIMMING_BACKLIGHT_STEPSIZE 10
#endif




// ***********************************************************
// ANIMATIONS 
// ***********************************************************

/**
 * Duration in ms of a single animation frame
 */
#define ANIMATION_FRAME_DURATION 50


// Animation type when going to next page
#define ANIMATION_NEXT_PAGE_TYPE ANIMATION_TYPE_OVERLAY_RIGHT

// Number of frames in animation when going to the next page
#define ANIMATION_NEXT_PAGE_FRAMES 10



// Animation type when going to previous page
#define ANIMATION_PREVIOUS_PAGE_TYPE ANIMATION_TYPE_OVERLAY_LEFT 

// Number of frames in animation when going to the next page
#define ANIMATION_PREVIOUS_PAGE_FRAMES 10



// Animation type when text in page is changed
#define ANIMATION_TEXT_CHANGE_TYPE ANIMATION_TYPE_MATRIX

// Number of frames when text in page is changed
#define ANIMATION_TEXT_CHANGE_FRAMES 20



// ***********************************************************
// TEXT ALIGNMENT
// ***********************************************************

// Textausrichtung im Display
#define H_TEXT_ALIGNMENT TEXT_H_ALIGNMENT_CENTER
#define V_TEXT_ALIGNMENT TEXT_V_ALIGNMENT_MIDDLE

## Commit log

2025-01-07 Dumped current state before changing configuration to ESP
2025-01-19 Added fusion files and updated readme instructions on printing
    [Lower_part.stl, Lower_part_nobuttons.stl, Pushbutton_Cover.stl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]
2025-01-19 Added schematics and photos
    [schematics.fzz]
2025-01-19 Added assembly video
2025-01-21 Updated distance to display screws in order to have a tight fit of the display when no acrylic plate is used
    [Lower_part.stl, Lower_part_nobuttons.stl, Upper_part.stl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]
2025-03-07 Relayouted head
2026-01-24 Add print/.DS_Store to .gitignore
2026-01-24 Updated photos of finally assembled version
2026-02-04 Moved all components to standard folders for fusion exporter plugin
    [Lower_part.stl, Lower_part_nobuttons.stl, Pushbutton_base.stl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]
2026-02-04 Fresh fusion export by plugin
    [Lower_part.stl, Pushbutton_base.stl, Pushbutton_cover.stl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]
2026-02-09 Fix image and STL file references in README.md
